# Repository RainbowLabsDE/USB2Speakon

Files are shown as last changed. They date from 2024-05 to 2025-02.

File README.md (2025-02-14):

# USB2Speakon

A fully self contained, USB powered ~5W PMPO[^1] Class-D amplifier inside a Speakon connector.  
This adapter allows you to connect your phone / laptop / $USB-audio-host-capable device to any passive loudspeaker that accepts a Speakon plug.  
In my tests it reached volumes significantly above "room volume". Its output power is probably enough to host a small indoor party.

<p float="left" style="display: flex; flex-wrap: wrap; align-items: center;">
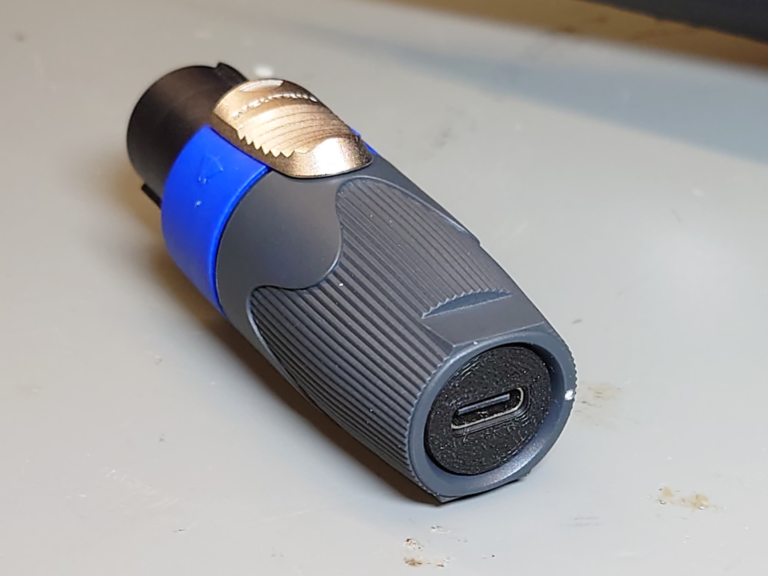
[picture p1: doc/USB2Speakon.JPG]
  &nbsp;
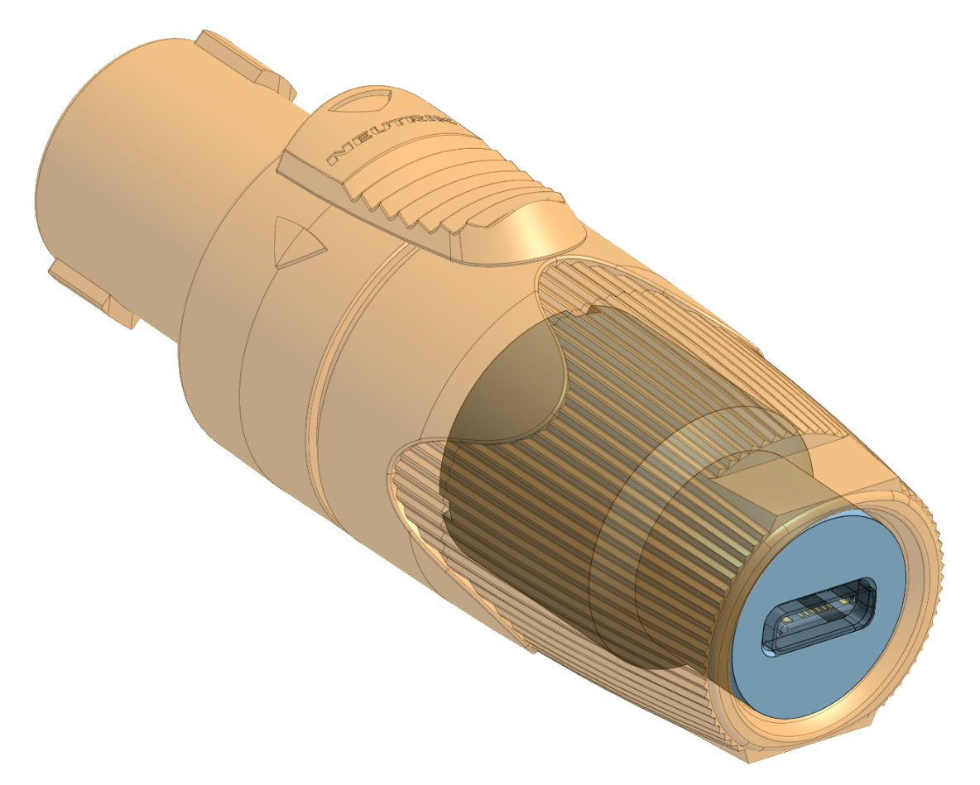
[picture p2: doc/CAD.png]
  &nbsp;
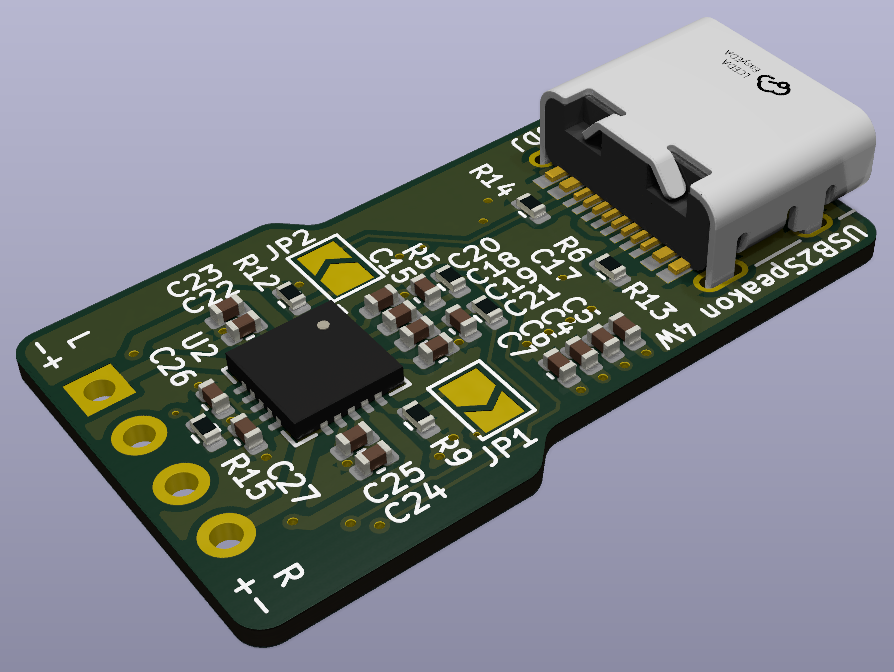
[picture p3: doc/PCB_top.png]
  &nbsp;
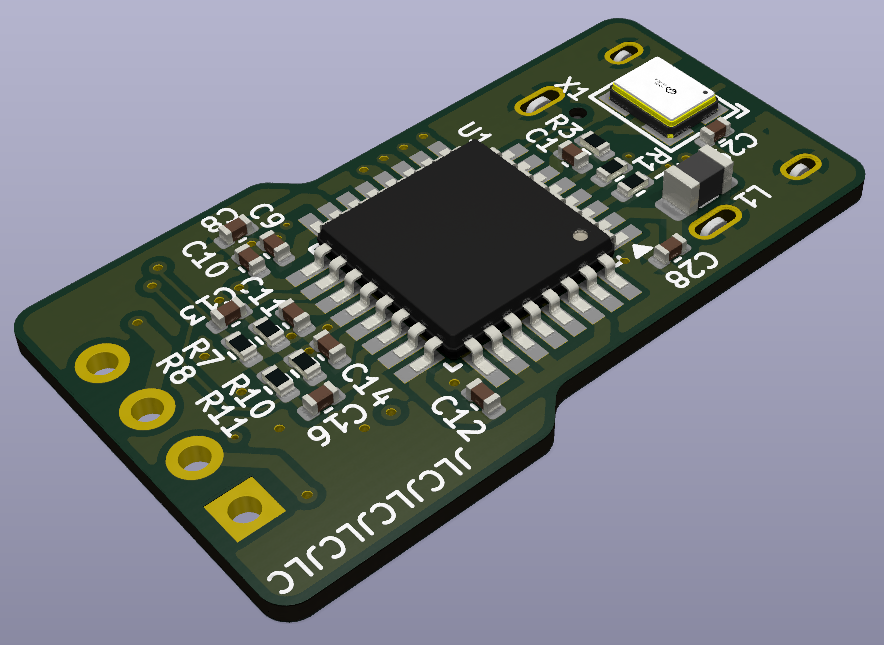
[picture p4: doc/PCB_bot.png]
  &nbsp;

</p>

### 3D-Printed Insert
The mechanical dimensions of the PCB and the insert were designed for a (now discontinued) [Neutrik speakON NL4FX](https://www.neutrik.com/en/product/nl4fx). 

The .step file can be found in the root of the repo and [the full design is on OnShape](https://cad.onshape.com/documents/68748694b7ef2772d9eb6de5/w/d122b393e16d1d6e538e0f7c/e/8ff2a0b1ab0e743580e4e000).

## Known "issues"
(Not really issues, as this project is more of an irl shitpost, so any issues are more or less by design :D)
- Android phones produce less volume than PCs. Idk why exactly, but it appears to be a software limitation, it's not limited by USB power. 
  - On some Android phones it's way too quiet though, there you can use [this shady volume booster app](https://play.google.com/store/apps/details?id=com.goodev.volume.booster) that actually manages to increase the output volume in that case.
- The project was designed for the now discontinued NL4FX. It is unclear if it would mechanically fit inside the new NL4FXX.
- ~~v0.1 has a 3225 footprint for a 6MHz crystal. No 6MHz crystal is available for that footprint tho.~~
  - This has been fixed in v0.2 with an oscillator.

## Pictures in use
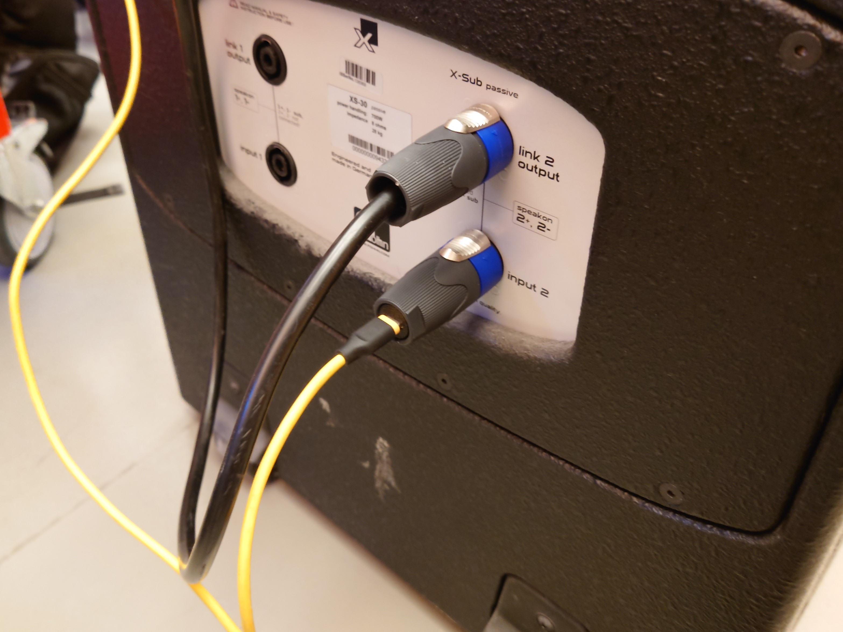
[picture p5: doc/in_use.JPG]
USB2Speakon in use


[^1]: ~~Peak Music Power Output~~ Panel Melting Power Once

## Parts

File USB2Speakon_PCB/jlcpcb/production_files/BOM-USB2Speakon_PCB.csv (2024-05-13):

Comment | Designator | Footprint | LCSC
USB_C_Receptacle_USB2.0_16P | J1 | USB_C_Receptacle_HRO_TYPE-C-31-M-12 | C165948
6MHz XO | X1 | OSC-SMD_4P-L3.2-W2.5-BL | C2901554
PCM2912A | U1 | TQFP-32_7x7mm_P0.8mm | C475497
3u3 | C10,C6 | C_0402_1005Metric | C695126
TPA2012D2RTJR | U2 | QFN-20-1EP_4x4mm_P0.5mm_EP2.7x2.7mm | C7717
1uH / <0.6Ω | L1 | L_0805_2012Metric | C99367
1u | C28 | C_0402_1005Metric
33k | R9 | R_0402_1005Metric
100p | C5 | C_0402_1005Metric
47n | C17 | C_0402_1005Metric
10u | C22 | C_0402_1005Metric
10u | C24 | C_0402_1005Metric
470n | C20 | C_0402_1005Metric
470n | C18 | C_0402_1005Metric
470n | C21 | C_0402_1005Metric
47n | C15 | C_0402_1005Metric
100p | C4 | C_0402_1005Metric
5k1 | R13 | R_0402_1005Metric
5k1 | R14 | R_0402_1005Metric
100n | C25 | C_0402_1005Metric
100 | R6 | R_0402_1005Metric
100n | C27 | C_0402_1005Metric
10u | C26 | C_0402_1005Metric
G0 | JP1 | SolderJumper-2_P1.3mm_Open_TrianglePad1.0x1.5mm
470n | C19 | C_0402_1005Metric
100 | R5 | R_0402_1005Metric
100n | C23 | C_0402_1005Metric
G1 | JP2 | SolderJumper-2_P1.3mm_Open_TrianglePad1.0x1.5mm
33k | R12 | R_0402_1005Metric
100n | C7 | C_0402_1005Metric
33k | R7 | R_0402_1005Metric
33k | R10 | R_0402_1005Metric
22 | R2 | R_0402_1005Metric
1u | C8 | C_0402_1005Metric
33k | R11 | R_0402_1005Metric
100n | C9 | C_0402_1005Metric
33k | R15 | R_0402_1005Metric
33k | R8 | R_0402_1005Metric
10u | C16 | C_0402_1005Metric
22 | R1 | R_0402_1005Metric
1k5 | R3 | R_0402_1005Metric
1u | C14 | C_0402_1005Metric
1u | C12 | C_0402_1005Metric
10u | C13 | C_0402_1005Metric
1u | C1 | C_0402_1005Metric
1u | C11 | C_0402_1005Metric
100n | C29 | C_0402_1005Metric

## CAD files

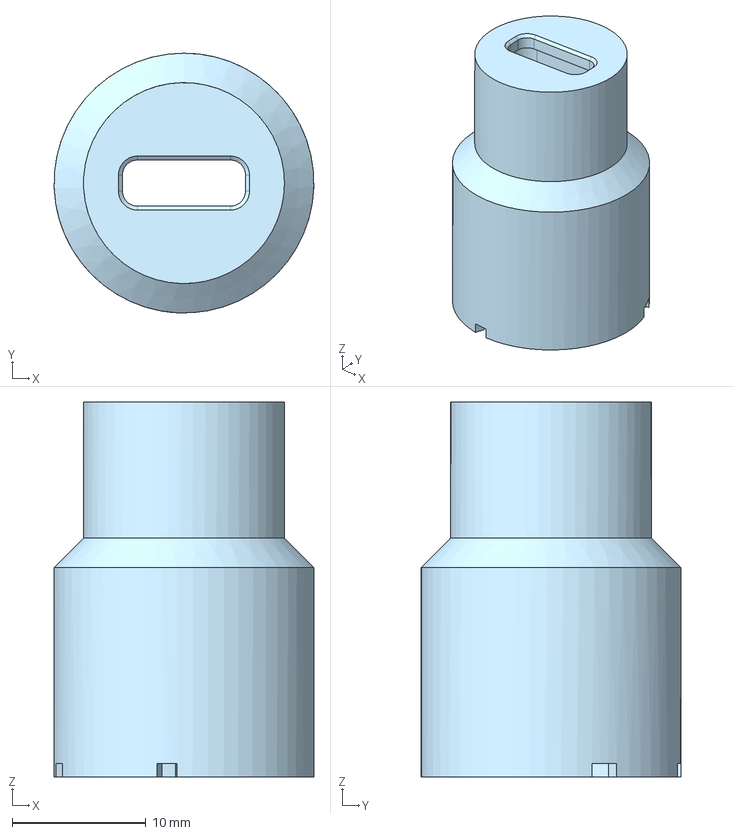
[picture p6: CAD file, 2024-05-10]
USB2Speakon_Holder.step
19.4 x 19.4 x 28.0 mm

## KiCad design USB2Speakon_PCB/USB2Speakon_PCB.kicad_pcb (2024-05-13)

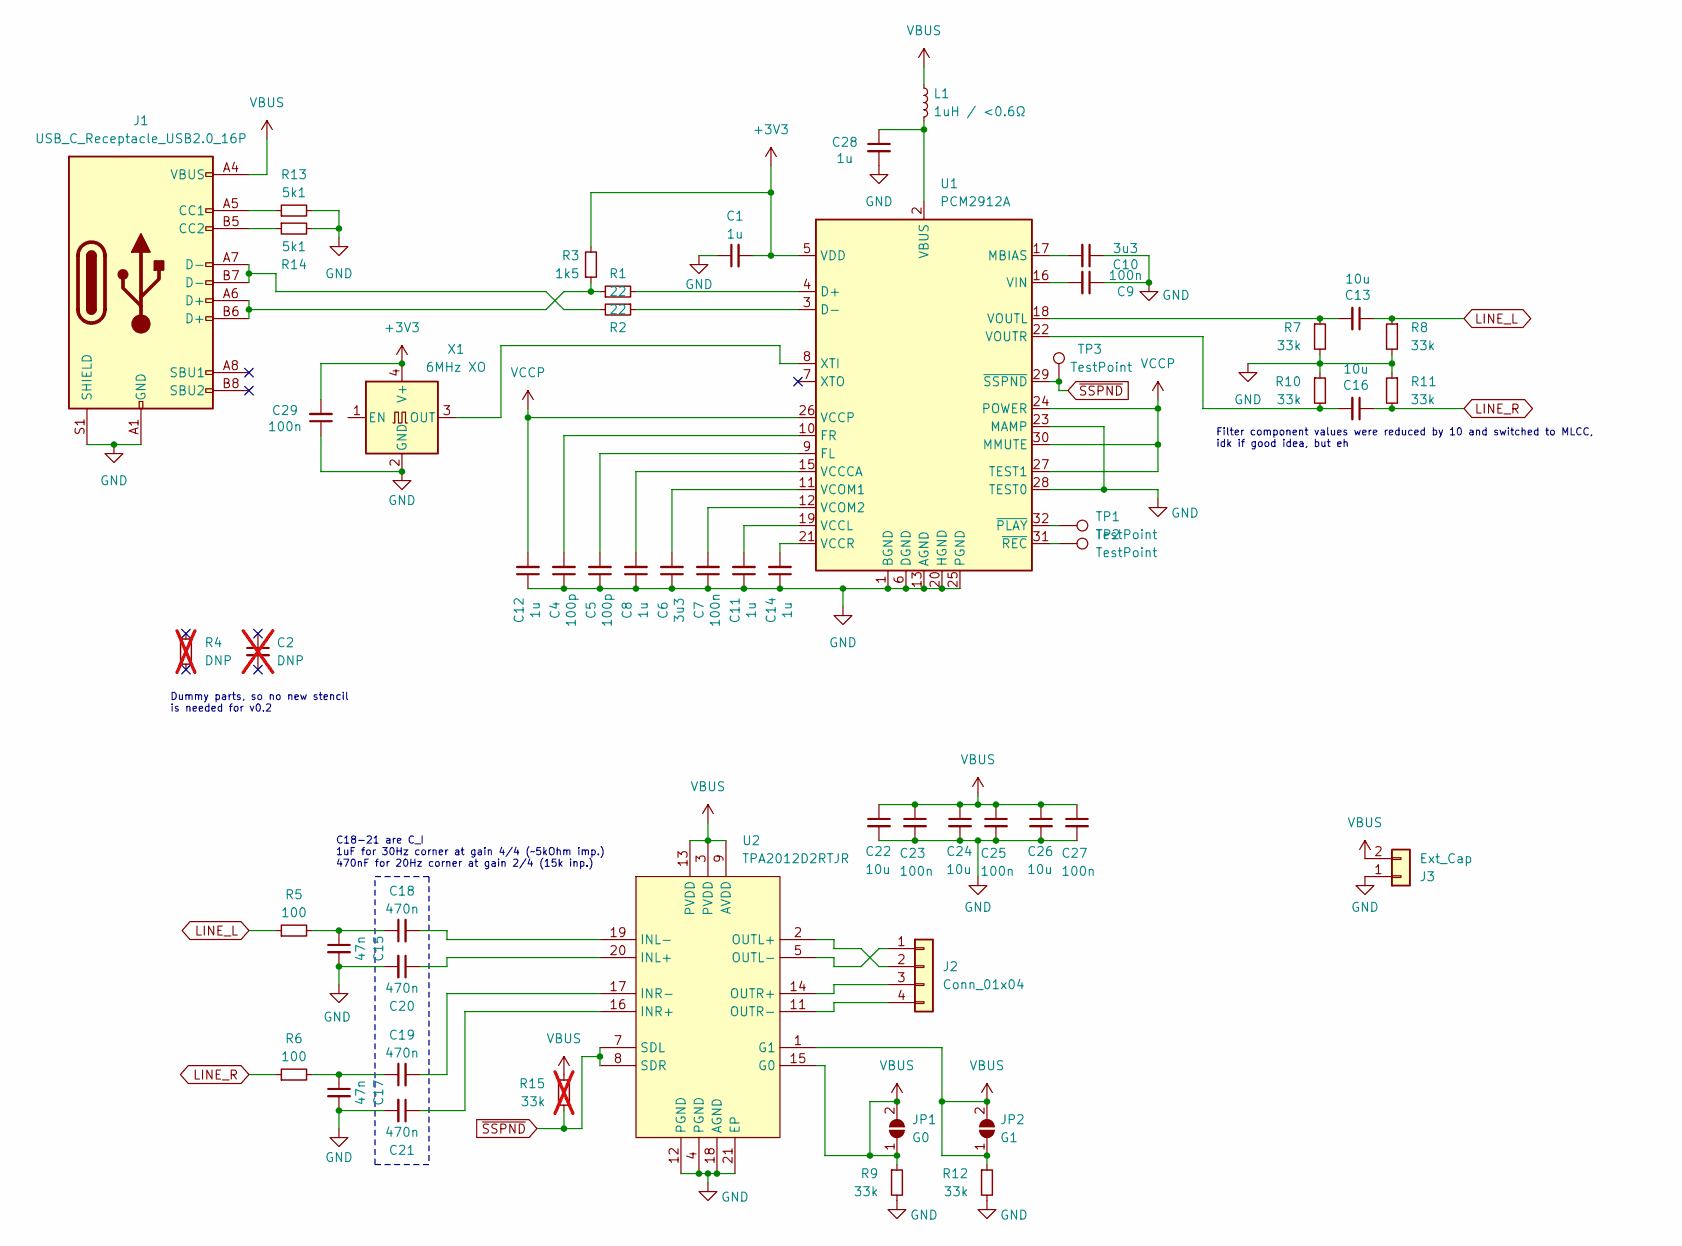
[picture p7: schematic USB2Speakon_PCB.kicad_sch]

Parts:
C1, C8, C11, C12, C14, C28: 1u; C_0402_1005Metric
C2: DNP; C_0402_1005Metric; not fitted
C4, C5: 100p; C_0402_1005Metric
C6, C10: 3u3; C_0402_1005Metric
C7, C9, C23, C25, C27, C29: 100n; C_0402_1005Metric
C13, C16, C22, C24, C26: 10u; C_0402_1005Metric
C15, C17: 47n; C_0402_1005Metric
C18, C19, C20, C21: 470n; C_0402_1005Metric
J1: USB_C_Receptacle_USB2.0_16P; USB_C_Receptacle_HRO_TYPE-C-31-M-12
J2: Conn_01x04; PinHeader_1x04_P2.54mm_Vertical
J3: Ext_Cap; PinSocket_1x02_P2.54mm_Vertical
JP1: G0; SolderJumper-2_P1.3mm_Open_TrianglePad1.0x1.5mm
JP2: G1; SolderJumper-2_P1.3mm_Open_TrianglePad1.0x1.5mm
L1: 1uH / <0.6Ω; L_0805_2012Metric; LCSC C99367
R1, R2: 22; R_0402_1005Metric
R3: 1k5; R_0402_1005Metric
R4: DNP; R_0402_1005Metric; not fitted
R5, R6: 100; R_0402_1005Metric
R7, R8, R9, R10, R11, R12: 33k; R_0402_1005Metric
R13, R14: 5k1; R_0402_1005Metric
R15: 33k; R_0402_1005Metric; not fitted
TP1, TP2, TP3: TestPoint; TestPoint_Pad_D1.0mm
U1: PCM2912A; TQFP-32_7x7mm_P0.8mm
U2: TPA2012D2RTJR; QFN-20-1EP_4x4mm_P0.5mm_EP2.7x2.7mm; LCSC Part C7717
X1: 6MHz XO; OSC-SMD_4P-L3.2-W2.5-BL

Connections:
+3V3: C1.2, C29.2, R3.2, U1.5 (VDD), X1.4 (V+)
GND: C1.1, C4.1, C5.1, C6.1, C7.1, C8.1, C9.1, C10.1, C11.1, C12.1, C14.1, C15.2, C17.2, C20.2, C21.2, C22.2, C23.2, C24.2, C25.2, C26.2, C27.2, C28.2, C29.1, J1.A1 (GND), J1.A12 (GND), J1.B1 (GND), J1.B12 (GND), J1.S1 (SHIELD), J3.1, R7.2, R8.2, R9.2, R10.1, R11.1, R12.2, R13.2, R14.2, U1.1 (BGND), U1.6 (DGND), U1.13 (AGND), U1.20 (HGND), U1.23 (MAMP), U1.25 (PGND), U1.28 (TEST0), U2.4 (PGND), U2.12 (PGND), U2.18 (AGND), U2.21 (EP), X1.2 (GND)
LINE_L: C13.1, R5.1, R8.1
LINE_R: C16.1, R6.1, R11.2
unnamed: C15.1, C18.1, R5.2
unnamed: C17.1, C19.1, R6.2
unnamed: J1.A5 (CC1), R13.1
unnamed: J1.B5 (CC2), R14.1
unnamed: J1.A6 (D+), J1.B6 (D+), R1.1, R3.1
unnamed: J1.A7 (D-), J1.B7 (D-), R2.2
unnamed: J2.1, U2.5 (OUTL-)
unnamed: J2.2, U2.2 (OUTL+)
unnamed: J2.3, U2.14 (OUTR+)
unnamed: J2.4, U2.11 (OUTR-)
unnamed: R1.2, U1.4 (D+)
unnamed: R2.1, U1.3 (D-)
unnamed: C5.2, U1.9 (FL)
unnamed: C4.2, U1.10 (FR)
unnamed: C10.2, U1.17 (MBIAS)
unnamed: C28.1, L1.2, U1.2 (VBUS)
unnamed: C8.2, U1.15 (VCCCA)
unnamed: C11.2, U1.19 (VCCL)
unnamed: C14.2, U1.21 (VCCR)
unnamed: C6.2, U1.11 (VCOM1)
unnamed: C7.2, U1.12 (VCOM2)
unnamed: C9.2, U1.16 (VIN)
unnamed: C13.2, R7.1, U1.18 (VOUTL)
unnamed: C16.2, R10.2, U1.22 (VOUTR)
unnamed: U1.8 (XTI), X1.3 (OUT)
unnamed: TP1.1, U1.32 (~PLAY)
unnamed: TP2.1, U1.31 (~REC)
unnamed: C20.1, U2.20 (INL+)
unnamed: C18.2, U2.19 (INL-)
unnamed: C21.1, U2.16 (INR+)
unnamed: C19.2, U2.17 (INR-)
VBUS: C22.1, C23.1, C24.1, C25.1, C26.1, C27.1, J1.A4 (VBUS), J1.A9 (VBUS), J1.B4 (VBUS), J1.B9 (VBUS), J3.2, JP1.1 (A), JP1.2 (B), JP2.1 (A), JP2.2 (B), L1.1, R9.1, R12.1, R15.1, U2.1 (G1), U2.3 (PVDD), U2.9 (AVDD), U2.13 (PVDD), U2.15 (G0)
VCCP: C12.2, U1.24 (POWER), U1.26 (VCCP), U1.27 (TEST1), U1.30 (MMUTE)
~SSPND: R15.2, TP3.1, U1.29 (~SSPND), U2.7 (SDL), U2.8 (SDR)

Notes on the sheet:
C18-21 are C_I 1uF for 30Hz corner at gain 4/4 (~5kOhm imp.) 470nF for 20Hz corner at gain 2/4 (15k inp.)
Filter component values were reduced by 10 and switched to MLCC, idk if good idea, but eh
Dummy parts, so no new stencil is needed for v0.2

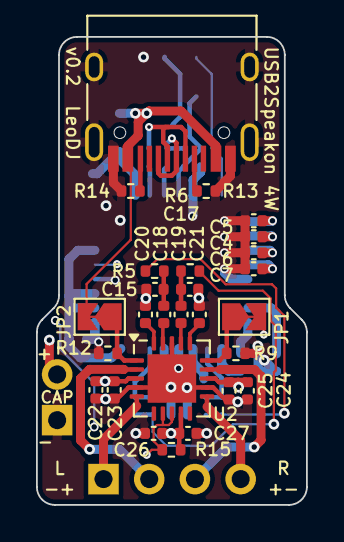
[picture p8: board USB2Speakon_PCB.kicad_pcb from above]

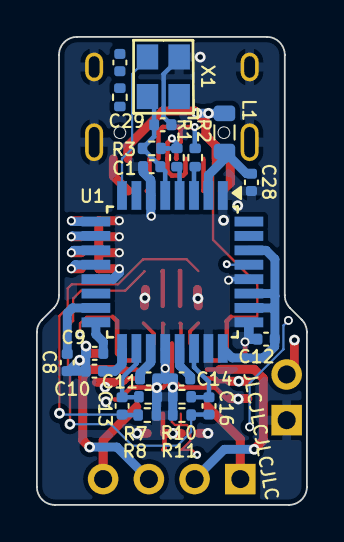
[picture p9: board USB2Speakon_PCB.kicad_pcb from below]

Board: 4 copper layers, 15.0 x 26.0 mm, 52 parts (23 on the bottom side), 36 nets.

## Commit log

2024-03-12 rough layout of v0.1 done
    [USB2Speakon_PCB.kicad_pcb, USB2Speakon_PCB.kicad_sch]
2024-03-12 add production files (and some minor tweaks)
    [BOM-USB2Speakon_PCB.csv, USB2Speakon_PCB.kicad_pcb, USB2Speakon_PCB.kicad_sch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]
2024-05-10 some minor changes, idk
    [USB2Speakon_PCB.kicad_pcb]
2024-05-10 add readme + license
    [USB2Speakon_Holder.step]
2024-05-13 replace crystal with oscillator and add solder pads for a capacitor
    [BOM-USB2Speakon_PCB.csv, USB2Speakon_PCB.kicad_pcb, USB2Speakon_PCB.kicad_sch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]
